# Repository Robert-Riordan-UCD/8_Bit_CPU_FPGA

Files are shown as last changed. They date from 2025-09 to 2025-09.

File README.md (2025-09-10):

# 8 Bit FPGA CPU

This is an 8-bit CPU design running on a Tang Nano 9k FPGA. The CPU design is based on [Ben Eaters Breadboard CPU](https://eater.net/8bit), which is based on the [Simple As Possible Computer](https://en.wikipedia.org/wiki/Simple-As-Possible_computer).

The CPU is made of 11 modules, which are designed in SystemVerilog and verified using [pyuvm](https://github.com/pyuvm/pyuvm).

This is a gif of the CPU calculating the fibonacci sequence and displaying it (in hexadecimal).
Video of the CPU calculating the fibonacci sequence

# Getting Started

This project is not fully complete yet and is currently only tested on my personal laptop and raspberry pi. However, this is the current process. (I am developing on Ubuntu 24 and used [this](https://www.geeklan.co.uk/?p=2919) guide to get up and running using an open source toolchain)

## Installation and Setup

The following programs are required:
1. ```yosys``` for synthisis.
2. ```nextpnr``` for place and route, and bitstream generation.
3. ```openFPGALoader``` for loading the bitstream.

```sudo apt insatll yosys nextpnr-gowin openfpgaloader```

Clone and navigate to the repository

```
git clone https://github.com/Robert-Riordan-UCD/8_Bit_CPU_FPGA
cd ./8_Bit_CPU_FPGA/
```

## Running

```make all upload```

## Testing

```pyuvm``` is required for testing.

```sudo apt install pyuvm```

To test each module navigate to the verif directory for that module and run make.

```
cd ./verif/<module>/
make
```

# Current Design Status

| Module                  | RTL | Verified | Runs on FPGA |
| :---------------------- | :-: | :-: | :-: |
| Clock                   |✅|✅|✅|
| Program Counter         |✅|✅|✅|
| A register              |✅|✅|✅|
| B Register              |✅|✅|✅|
| Memory Address Register |✅|✅|✅|
| Instruction Register    |✅|✅|✅|
| Random Access Memory    |✅|✅|✅|
| Arithmetic Logic Unit   |✅|✅|✅|
| Control                 |✅|✅|✅|
| Output                  |✅|✅|✅|
| Bus                     |✅|✅|✅|
| Bootloader              |✅|✅|✅|
||||
| Top                     |✅|❌|✅|

The output is currently in hexadecimal, because there was not enough LUTs on the Tang Nano 9k to implement a naive approach to decimal conversion using division. I will hopefully update this to a better approach soon.

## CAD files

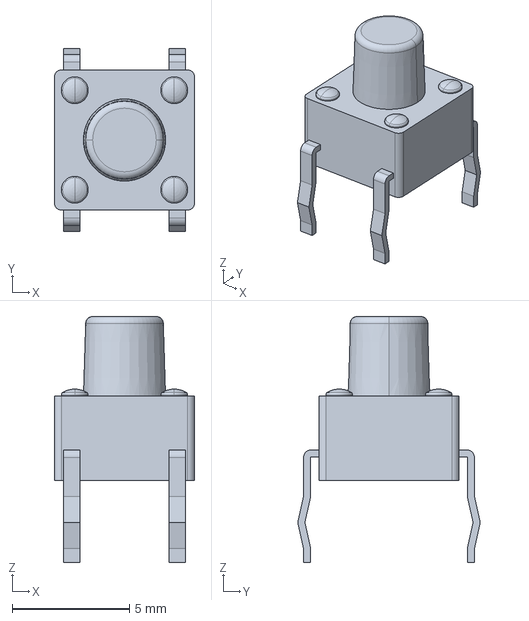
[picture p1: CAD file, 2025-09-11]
pcb/footprints/c-1-1825910-0-c-3d.stp
5.99 x 7.80 x 10.5 mm

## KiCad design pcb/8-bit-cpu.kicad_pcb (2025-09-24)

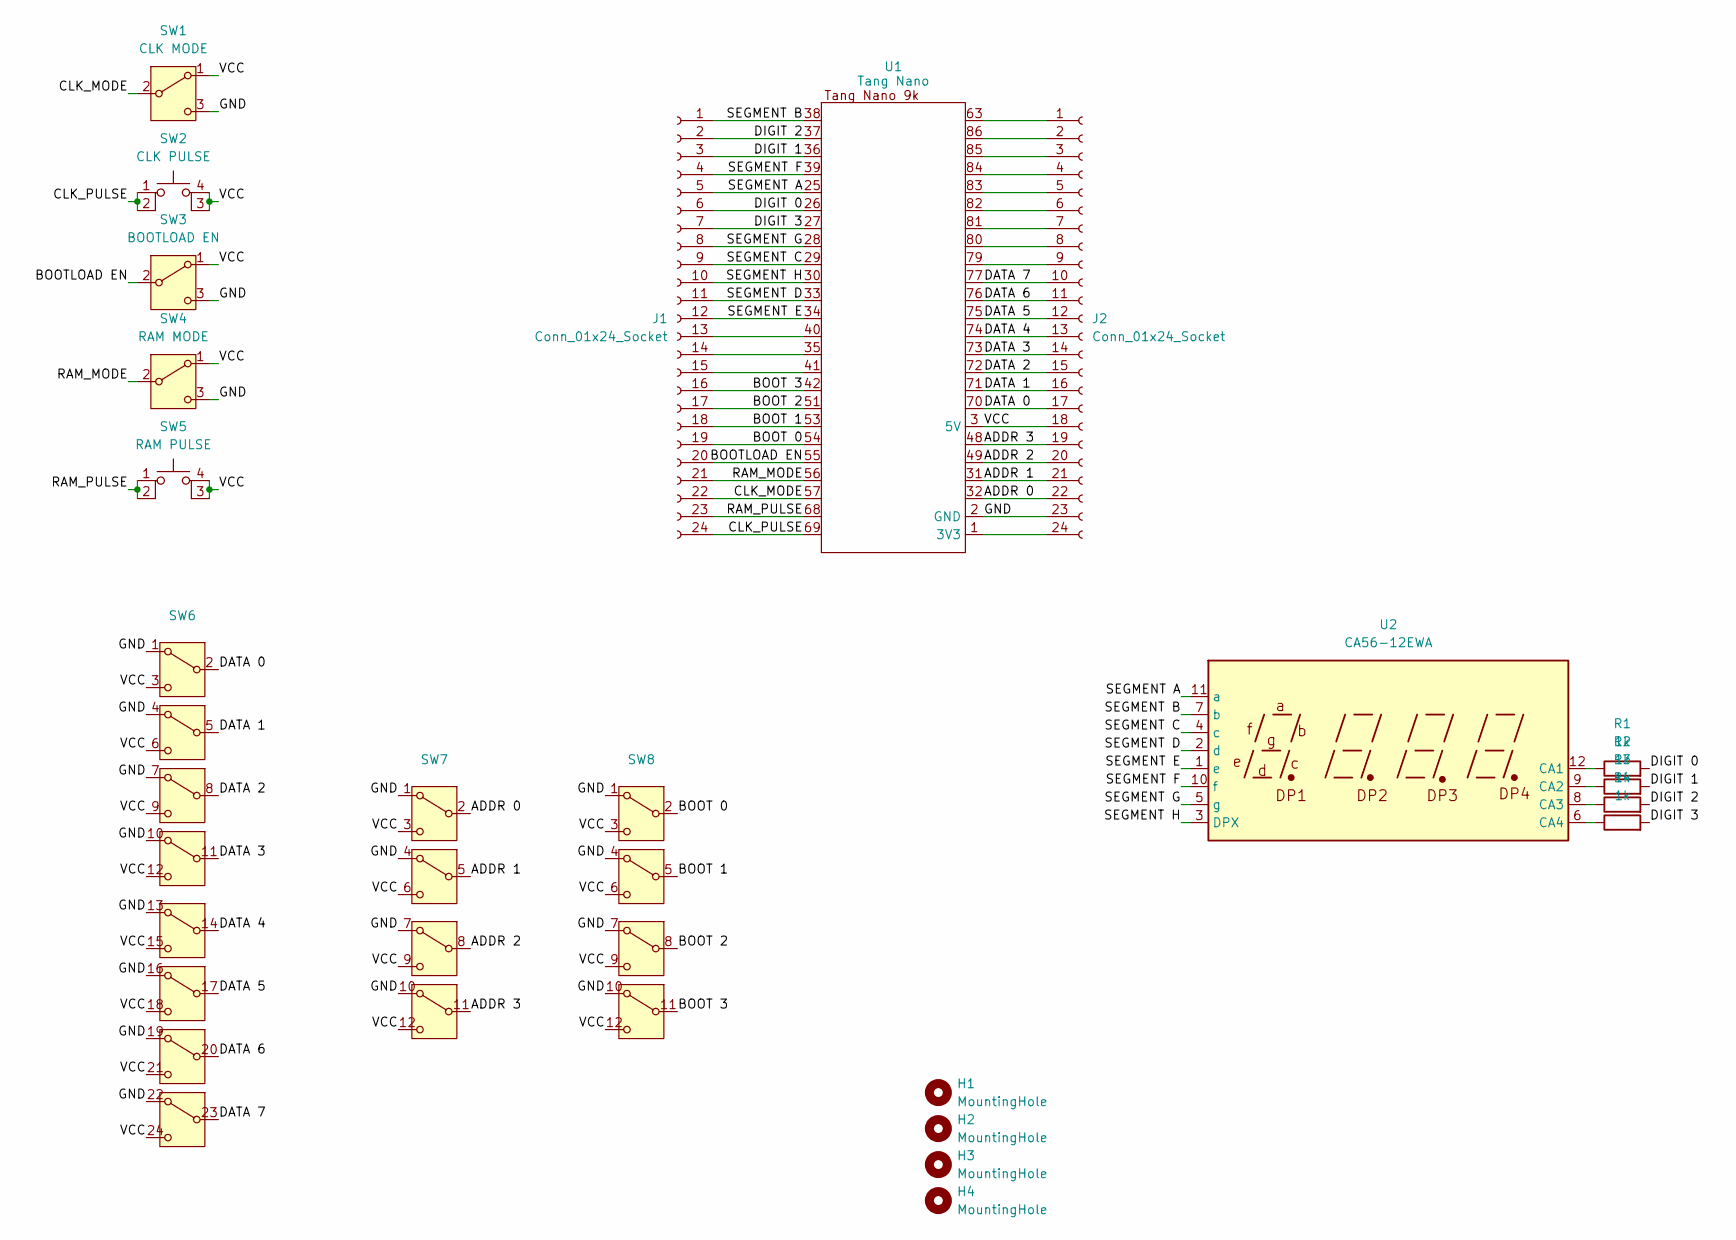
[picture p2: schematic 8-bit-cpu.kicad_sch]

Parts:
H1, H2, H3, H4: MountingHole; MountingHole_3.2mm_M3
J1, J2: Conn_01x24_Socket; PinHeader_1x24_P2.54mm_Vertical
R1, R2, R3, R4: 1k; R_Axial_DIN0309_L9.0mm_D3.2mm_P12.70mm_Horizontal
SW1: CLK MODE; DoubleThrowSwitch
SW2: CLK PULSE; tactile_switch
SW3: BOOTLOAD EN; DoubleThrowSwitch
SW4: RAM MODE; DoubleThrowSwitch
SW5: RAM PULSE; tactile_switch
SW6: 8xDoubleThrowSwitch
SW7, SW8: 4xDoubleThrowSwitch
U1: Tang Nano; TangNano
U2: CA56-12EWA

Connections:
/ADDR 0: J2.22, SW7.2, U1.32
/ADDR 1: J2.21, SW7.5, U1.31
/ADDR 2: J2.20, SW7.8, U1.49
/ADDR 3: J2.19, SW7.11, U1.48
/BOOT 0: J1.19, SW8.2, U1.54
/BOOT 1: J1.18, SW8.5, U1.53
/BOOT 2: J1.17, SW8.8, U1.51
/BOOT 3: J1.16, SW8.11, U1.42
/BOOTLOAD EN: J1.20, SW3.2 (B), U1.55
/CLK_MODE: J1.22, SW1.2 (B), U1.57
/CLK_PULSE: J1.24, SW2.1, SW2.2, U1.69
/DATA 0: J2.17, SW6.2, U1.70
/DATA 1: J2.16, SW6.5, U1.71
/DATA 2: J2.15, SW6.8, U1.72
/DATA 3: J2.14, SW6.11, U1.73
/DATA 4: J2.13, SW6.14, U1.74
/DATA 5: J2.12, SW6.17, U1.75
/DATA 6: J2.11, SW6.20, U1.76
/DATA 7: J2.10, SW6.23, U1.77
/DIGIT 0: J1.6, R1.2, U1.26
/DIGIT 1: J1.3, R2.2, U1.36
/DIGIT 2: J1.2, R3.2, U1.37
/DIGIT 3: J1.7, R4.2, U1.27
/GND: J2.23, SW1.3 (C), SW3.3 (C), SW4.3 (C), SW6.1, SW6.4, SW6.7, SW6.10, SW6.13, SW6.16, SW6.19, SW6.22, SW7.1, SW7.4, SW7.7, SW7.10, SW8.1, SW8.4, SW8.7, SW8.10, U1.2 (GND)
/RAM_MODE: J1.21, SW4.2 (B), U1.56
/RAM_PULSE: J1.23, SW5.1, SW5.2, U1.68
/SEGMENT A: J1.5, U1.25, U2.11 (a)
/SEGMENT B: J1.1, U1.38, U2.7 (b)
/SEGMENT C: J1.9, U1.29, U2.4 (c)
/SEGMENT D: J1.11, U1.33, U2.2 (d)
/SEGMENT E: J1.12, U1.34, U2.1 (e)
/SEGMENT F: J1.4, U1.39, U2.10 (f)
/SEGMENT G: J1.8, U1.28, U2.5 (g)
/SEGMENT H: J1.10, U1.30, U2.3 (DPX)
/VCC: J2.18, SW1.1 (A), SW2.3 (K), SW2.4 (A), SW3.1 (A), SW4.1 (A), SW5.3 (K), SW5.4 (A), SW6.3, SW6.6, SW6.9, SW6.12, SW6.15, SW6.18, SW6.21, SW6.24, SW7.3, SW7.6, SW7.9, SW7.12, SW8.3, SW8.6, SW8.9, SW8.12, U1.3 (5V)
unnamed: J1.13, U1.40
unnamed: J1.14, U1.35
unnamed: J1.15, U1.41
unnamed: J2.1, U1.63
unnamed: J2.2, U1.86
unnamed: J2.3, U1.85
unnamed: J2.4, U1.84
unnamed: J2.5, U1.83
unnamed: J2.6, U1.82
unnamed: J2.7, U1.81
unnamed: J2.8, U1.80
unnamed: J2.9, U1.79
unnamed: J2.24, U1.1 (3V3)
unnamed: R1.1, U2.12 (CA1)
unnamed: R2.1, U2.9 (CA2)
unnamed: R3.1, U2.8 (CA3)
unnamed: R4.1, U2.6 (CA4)

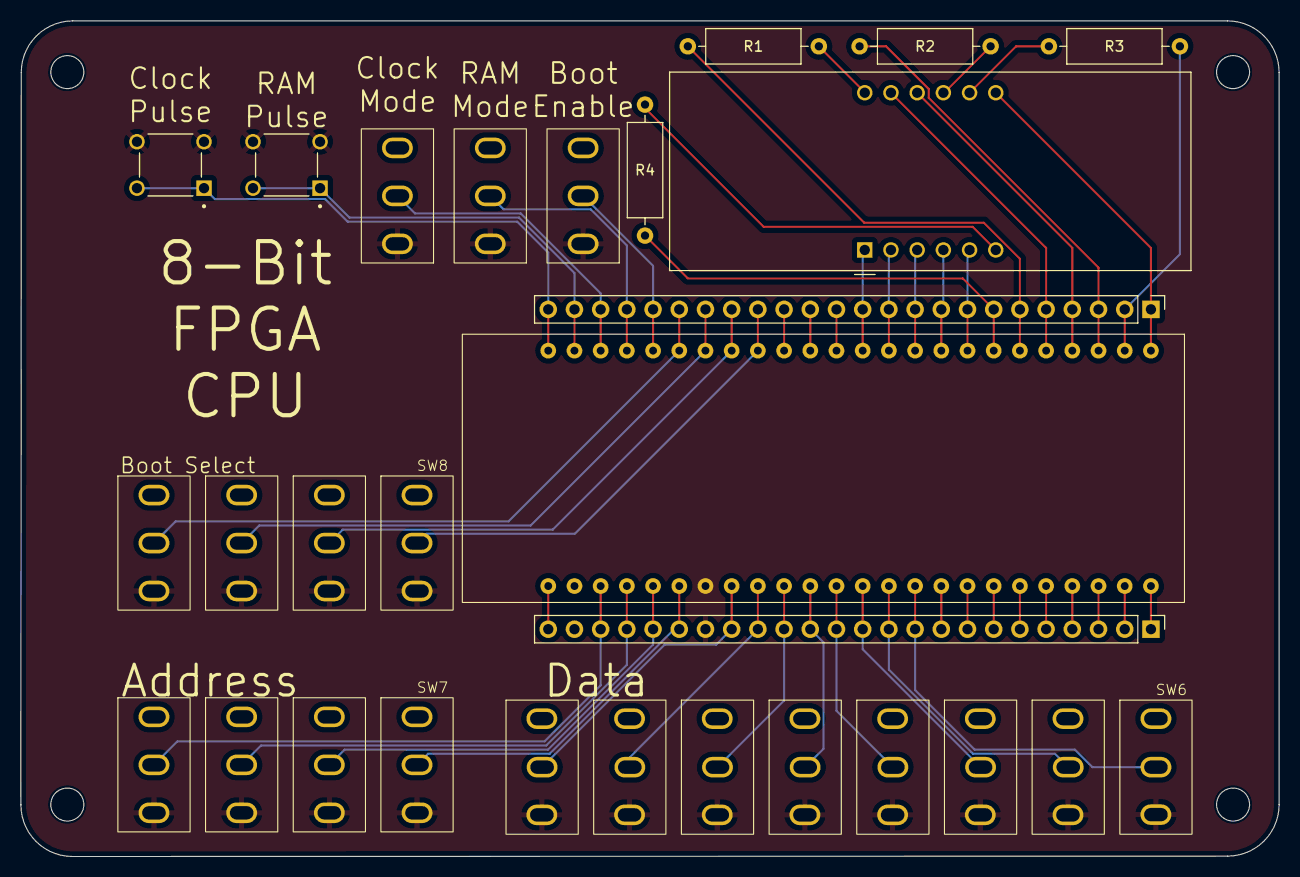
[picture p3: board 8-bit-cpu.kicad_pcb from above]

Board: 2 copper layers, 122.0 x 81.0 mm, 20 parts (0 on the bottom side), 52 nets.

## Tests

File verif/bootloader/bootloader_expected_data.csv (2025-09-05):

program | address | instruction | data
0 | 0 | load im | 0
0 | 1 | add | 15
0 | 2 | out
0 | 3 | jump | 1
1 | 0 | load im | 0
1 | 1 | add | 15
1 | 2 | jump c | 10
1 | 3 | out
1 | 4 | store a | 13
1 | 5 | load a | 14
1 | 6 | store a | 15
1 | 7 | load a | 13
1 | 8 | store a | 14
1 | 9 | jump | 1
1 | 10 | halt
1 | 14 |  | 1
1 | 15 |  | 0

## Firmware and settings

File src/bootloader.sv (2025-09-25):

/*
    Populate ram with a program on reset
    Write an address followed by the data for each location in ram according to the selected program
*/

`define NUM_PROGRAMS 4

module bootloader (
    input clk,
    input rst,
    input [$clog2(`NUM_PROGRAMS)-1:0] program_select,
    input enable_bootload,

    output logic [7:0] data,
    output logic bootload_address,
    output logic bootload_ram
);
    logic addr_or_ram=0;
    logic [3:0] addr=0;
    logic complete=0;

    logic [5:0] counter;
    always_comb begin
        {complete, addr, addr_or_ram} = counter;        
    end

    logic [7:0] programs [`NUM_PROGRAMS][16];

    initial begin
        /* Initialize to 0 */
        integer prog;
        integer addr;
        for (prog = 0; prog < `NUM_PROGRAMS; prog = prog + 1) begin
            for (addr = 0; addr < 16; addr = addr + 1) begin
                programs[prog][addr] = {`NOOP, 4'b0000};
            end
		end

        /* Count in 1s */
        // Program
        programs[0][0] = {`ADD,     4'b1111};
        programs[0][1] = {`OUT,     4'b0000};
        programs[0][2] = {`JUMP,    4'b0000};
        // Data
        programs[0][15] =    {8'b00000001};

        /* Alternate between 0 and F */
        // Program
        programs[1][0] = {`LOAD_IM, 4'b0000};
        programs[1][1] = {`OUT,     4'b0000};
        programs[1][2] = {`NOOP,    4'b0000}; // NOOP so each digit get equal cycles
        programs[1][3] = {`LOAD_IM, 4'b1111};
        programs[1][4] = {`OUT,     4'b0000};
        programs[1][5] = {`JUMP,    4'b0000};

        /* Fibonacci */
        // Program
        programs[2][0] = {`ADD,     4'b1111};
        programs[2][1] = {`JUMPC,   4'b1001};
        programs[2][2] = {`OUT,     4'b0000};
        programs[2][3] = {`STORE_A, 4'b1101};
        programs[2][4] = {`LOAD_A,  4'b1110};
        programs[2][5] = {`STORE_A, 4'b1111};
        programs[2][6] = {`LOAD_A,  4'b1101};
        programs[2][7] = {`STORE_A, 4'b1110};
        programs[2][8] = {`JUMP,    4'b0000};
        programs[2][9] = {`HALT,    4'b0000};
        // Data
        programs[2][14] = {8'b00000001};
        programs[2][15] = {8'b00000000};

        /* Multiply 6 by 11 */
        // = 66 -> 0x42
        // Program
        programs[3][0] = {`LOAD_A,  4'd15};
        programs[3][1] = {`STORE_A, 4'd13};
        programs[3][2] = {`LOAD_A,  4'd13};
        programs[3][3] = {`OUT,     4'b0};
        programs[3][4] = {`ADD,     4'd15};
        programs[3][5] = {`STORE_A, 4'd13};
        programs[3][6] = {`LOAD_A,  4'd14};
        programs[3][7] = {`SUB,     4'd12};
        programs[3][8] = {`JUMPZ,   4'd11};
        programs[3][9] = {`STORE_A, 4'd14};
        programs[3][10] = {`JUMP,   4'd2};
        programs[3][11] = {`HALT,   4'b0};
        // Data
        programs[3][12] = 8'b1;
        programs[3][13] = 8'b0; // SUM
        programs[3][14] = 8'd11; // B
        programs[3][15] = 8'd6; // A
    end

    always_ff @(posedge clk or posedge rst) begin
        if (rst) begin
            counter <= 0;
        end else if (~complete) begin
            counter <= counter+1;
        end else begin
            counter <= counter;
        end
    end

    always_comb begin
        if (enable_bootload & ~complete & ~rst) begin
            bootload_address = ~addr_or_ram;
            bootload_ram = addr_or_ram; 
        end else begin
            bootload_address = 0;
            bootload_ram = 0;
        end
    end
    
    always_comb begin
        if (bootload_address & ~bootload_ram) begin
            data = addr;
        end else if (~bootload_address & bootload_ram) begin
            data = programs[program_select][addr];
        end else begin
            data = 'b0;
        end
    end
    
endmodule

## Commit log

2025-07-13 Added edge case and operation sequences
2025-07-15 Added all current modules to top
2025-08-14 Switched PC to seperate input and output buses. PC running on FPGA
2025-08-14 Switched register to seperate input and output buses. I reg running on FPGA
2025-08-15 A/B registers running on FPGA. Added missing ram_bus_out wire
2025-08-19 Updated bootloader scoreboard and fixed errors in bootloader
    [bootloader_expected_data.csv]
2025-09-05 Updated bootloader coverage to use cocotb CoverPoint and CoverCross
    [bootloader_expected_data.csv]
2025-09-11 Fixed cont_addr getting program switches and removed unused signal
2025-09-11 PCB design
    [8-bit-cpu.kicad_pcb, 8-bit-cpu.kicad_sch, c-1-1825910-0-c-3d.stp]
2025-09-11 Added current limiting resistors to display
    [8-bit-cpu.kicad_pcb, 8-bit-cpu.kicad_sch]
2025-09-24 Moved boot select switch to clear HDMI port
    [8-bit-cpu.kicad_pcb]
2025-09-24 Reverse bit ordering to match PCB
2025-09-24 Switched to new 7 segment display with reverse polarity. Switched RAM pulse polarity to because it is using the onboard button now
